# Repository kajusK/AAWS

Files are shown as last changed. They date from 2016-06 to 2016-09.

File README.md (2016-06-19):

Weather Station
===============

Small weather station with many useful features. All mechanical parts
(anemometer, wind vane...) are 3D printed.

Measured values
---------------
* Wind speed (TODO resolution)
* Wind direction (+- 6 degrees)
* Temperature (-40 to 85 °C +-0,1°C)
* Pressure (300 to 1100 hPa +- 6hPa)
* Humidity (0 to 100 %RH +- 2%RH)
* Rain sensor
* Rain (TODO resolution mm/h)

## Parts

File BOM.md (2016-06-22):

Bill Of Material
================

Anemometer
----------
| Item			| Amount|
|---|---|
| Brass knurled nut M3	| 15	|
| Screw M3x10		| 3	|
| Screw M3x30		| 4	|
| Screw M3x25		| 2	|
| Grub screw M3x5	| 1	|
| Rod diameter 4mm	| 45 mm	|
| Bearing 624		| 2	|
| 5MM red LED		| 1	|
| 5MM photodiode	| 1	|

Wind Vane
---------
| Item			| Amount|
|---|---|
| Brass knurled nut M3	| 17	|
| Screw M3x10		| 3	|
| Screw M3x30		| 4	|
| Screw M3x25		| 4	|
| Grub screw M3x5	| 1	|
| Rod diameter 4mm	| 45 mm	|
| Bearing 624		| 2	|
| 5MM red LED		| 5	|
| 5MM photodiode	| 5	|

Rain gauge
----------
| Item			| Amount|
|---|---|
| Threaded rod M4	| 45 mm	|
| Brass knurled nut M3	| 14	|
| Piece of credit card	| 1	|
| Screw M3x10		| 4	|
| Screw M3x20		| 2	|
| Screw M3x45		| 4	|
| Pen spring		| 2	|
| Nut M3		| 2	|
| Washer M3		| 6	|

Sensors housing
---------------
| Item			| Amount|
|---|---|
| Threaded rod M3	| X mm	|
| Nut M3		| X mm	|
| Flower pot saucer	| 6	|
| Small computer fan	| 1	|

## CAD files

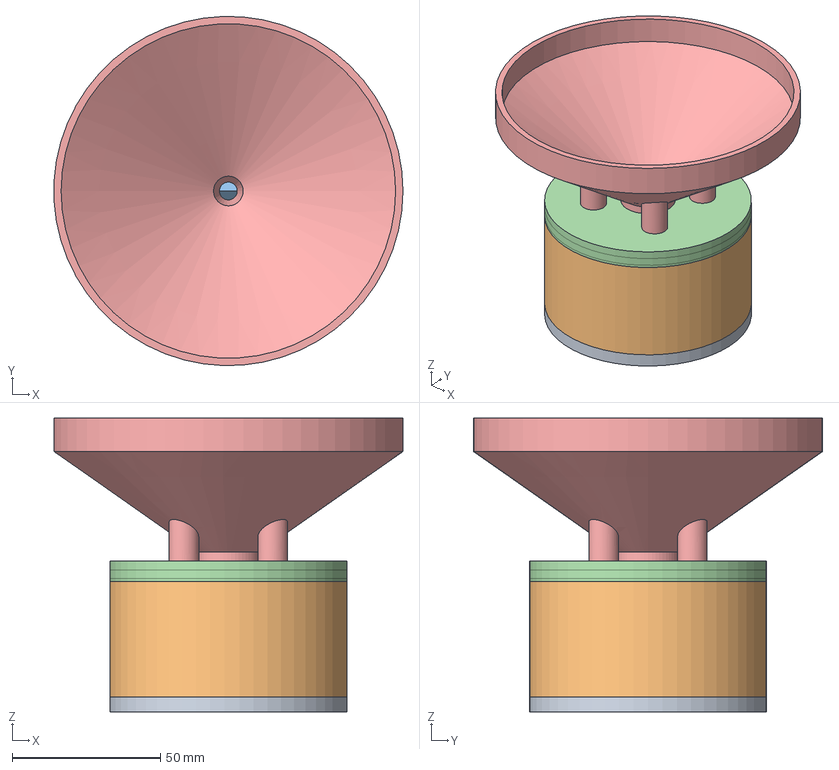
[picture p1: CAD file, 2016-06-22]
cad/rain_gauge/assembly.fcstd
117.9 x 118.0 x 99.3 mm
bottom_01
bucket_01
top_01
catcher_01

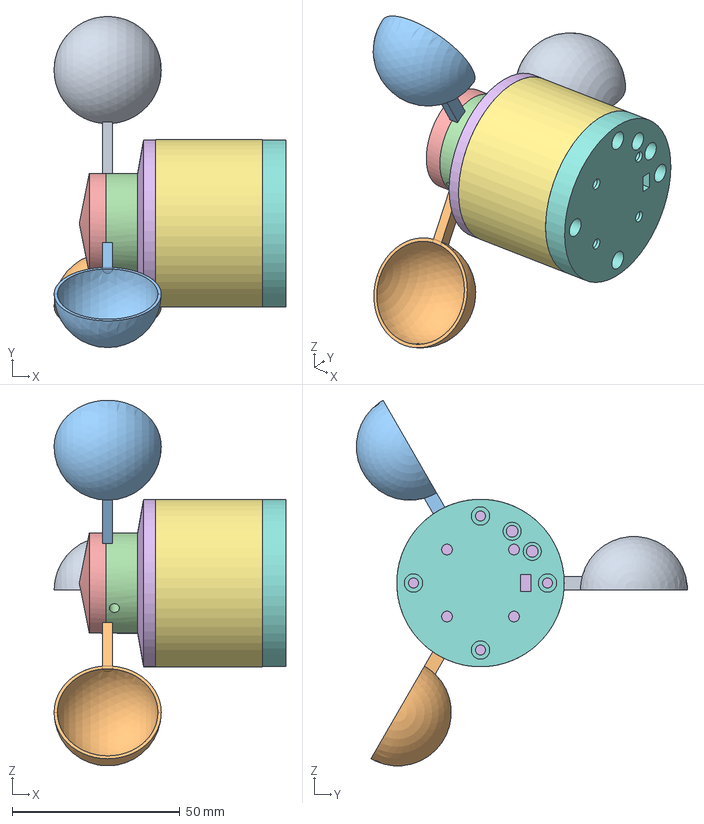
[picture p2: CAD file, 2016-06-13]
cad/anemometer/body/assembly.fcstd
69.2 x 98.8 x 109.1 mm
cup_01
cup_02
cup_03
base_01
top_01
body_top_01
body_bottom_01

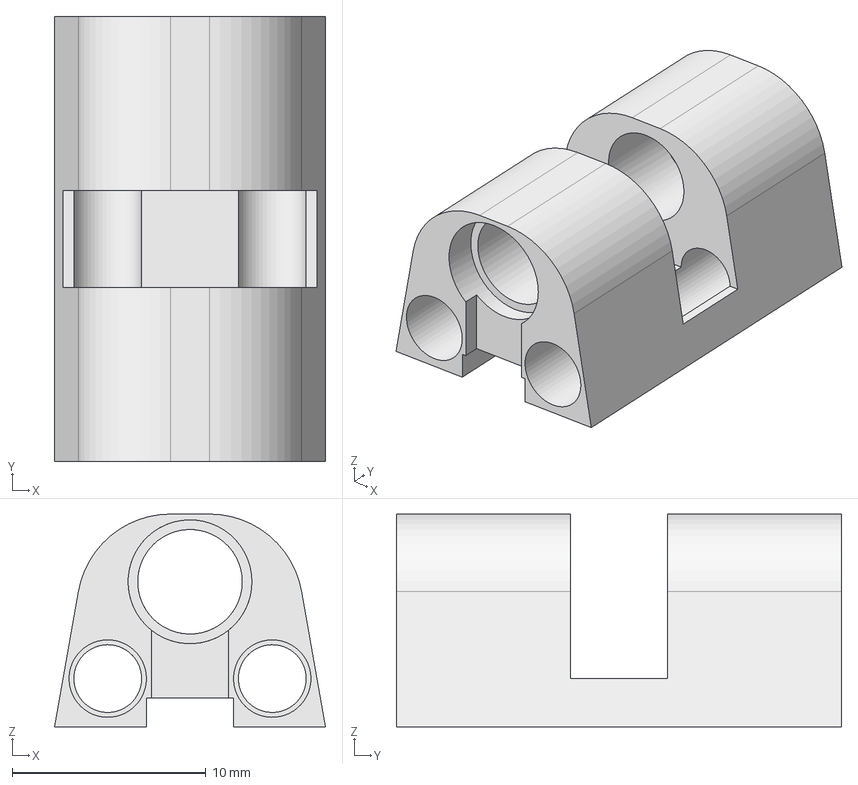
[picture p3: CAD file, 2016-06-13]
cad/anemometer/body/sensor_holder.fcstd
14.0 x 23.0 x 11.0 mm

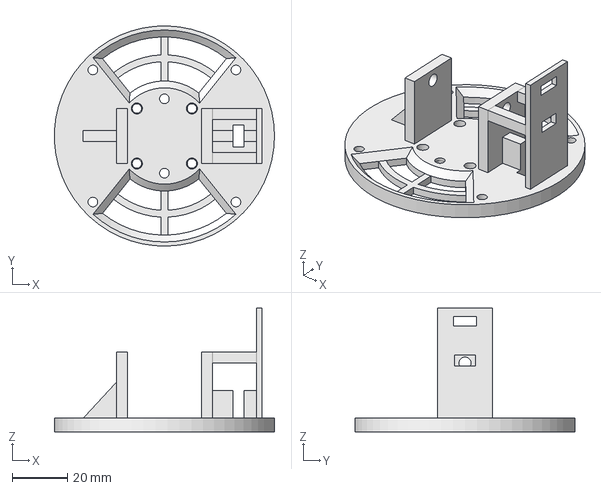
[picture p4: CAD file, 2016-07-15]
cad/rain_gauge/bottom.fcstd
79.9 x 80.0 x 45.0 mm

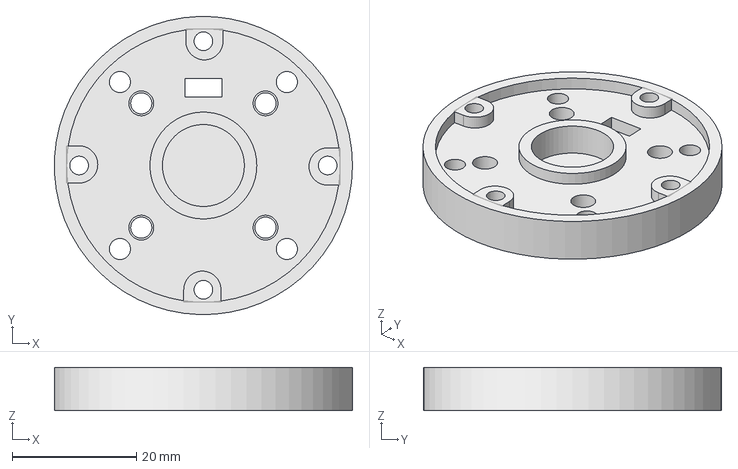
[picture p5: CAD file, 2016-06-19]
cad/wind_vane/body/body_bottom.fcstd
48.0 x 48.0 x 7.00 mm

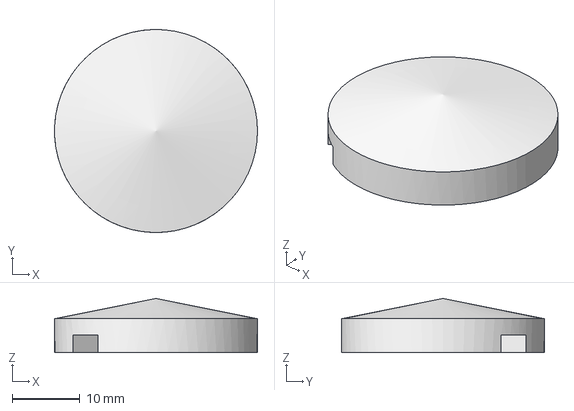
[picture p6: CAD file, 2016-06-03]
cad/wind_vane/top/top.fcstd
30.0 x 30.0 x 8.00 mm

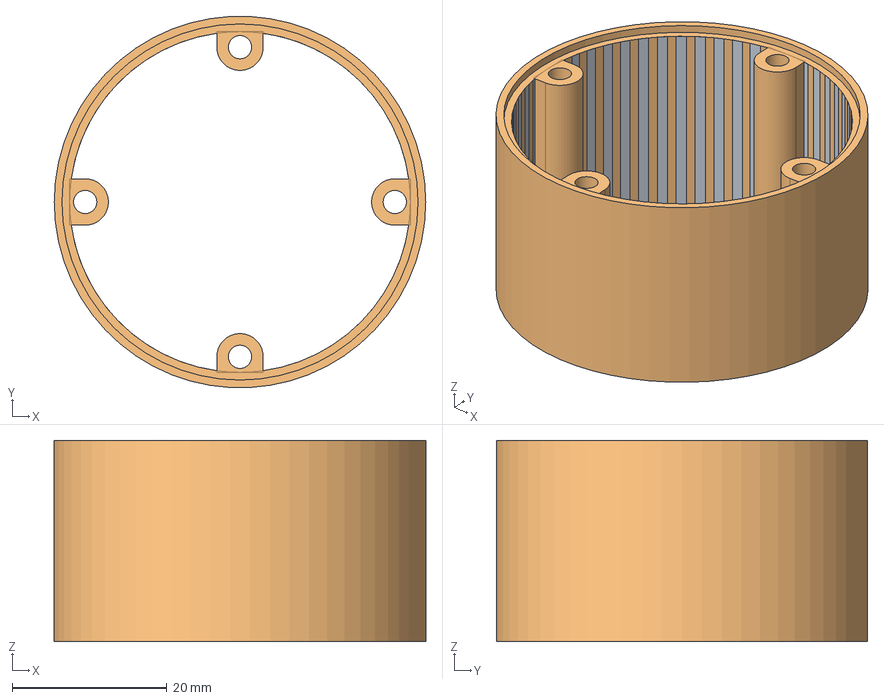
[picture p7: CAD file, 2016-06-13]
cad/anemometer/body/body.fcstd
48.0 x 47.9 x 26.0 mm
PolarPattern

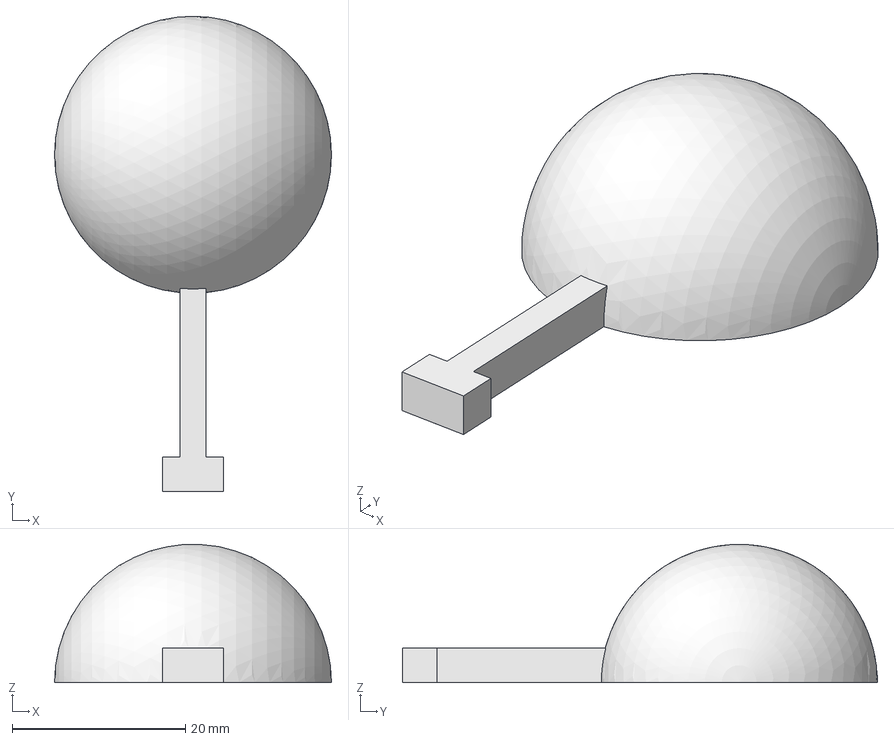
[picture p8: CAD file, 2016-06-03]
cad/anemometer/top/cup.fcstd
32.0 x 54.9 x 16.0 mm

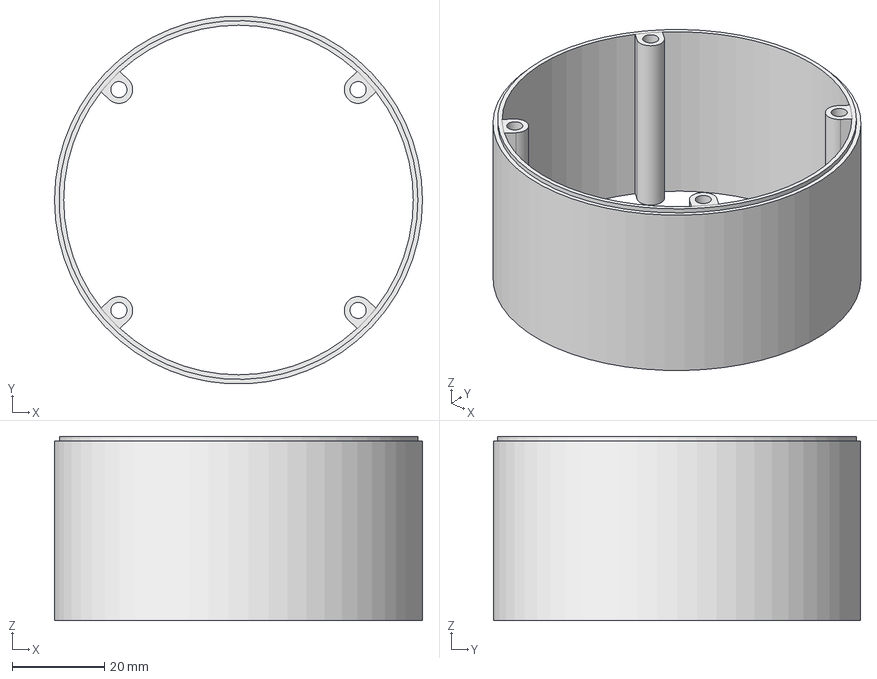
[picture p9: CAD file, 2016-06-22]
cad/rain_gauge/body.fcstd
80.0 x 79.9 x 40.0 mm

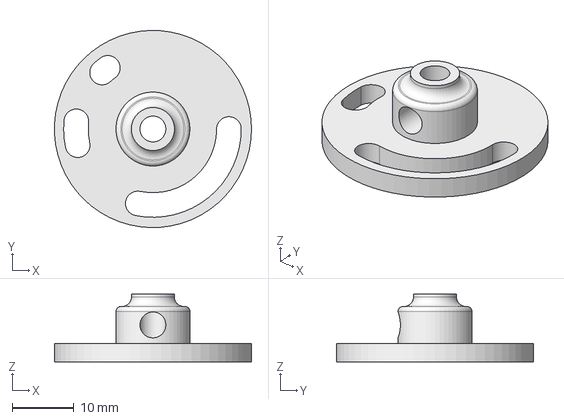
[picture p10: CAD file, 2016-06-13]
cad/wind_vane/body/signal_plate.fcstd
32.0 x 32.0 x 11.0 mm

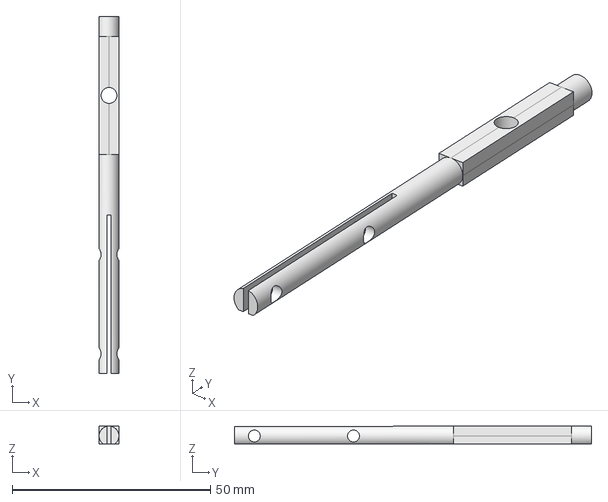
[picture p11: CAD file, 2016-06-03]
cad/wind_vane/top/rod.fcstd
5.00 x 90.0 x 4.50 mm

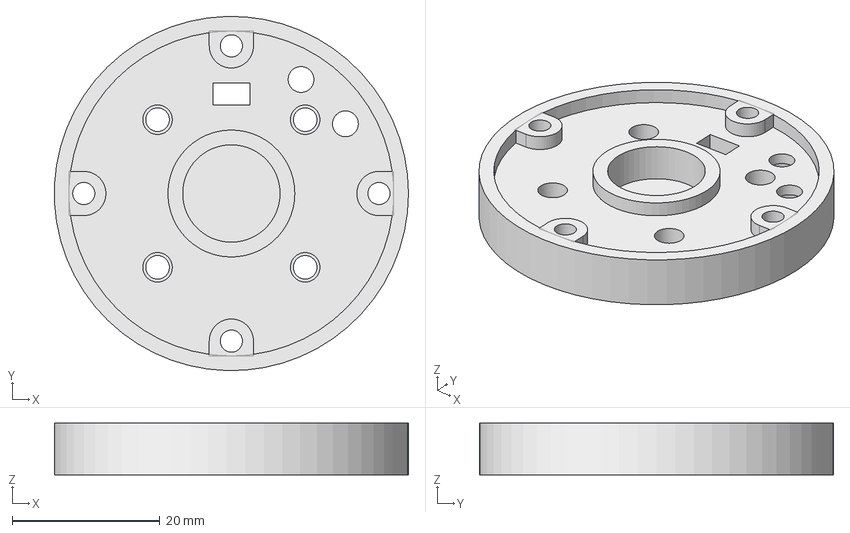
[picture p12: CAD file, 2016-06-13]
cad/anemometer/body/body_bottom.fcstd
48.0 x 48.0 x 7.00 mm

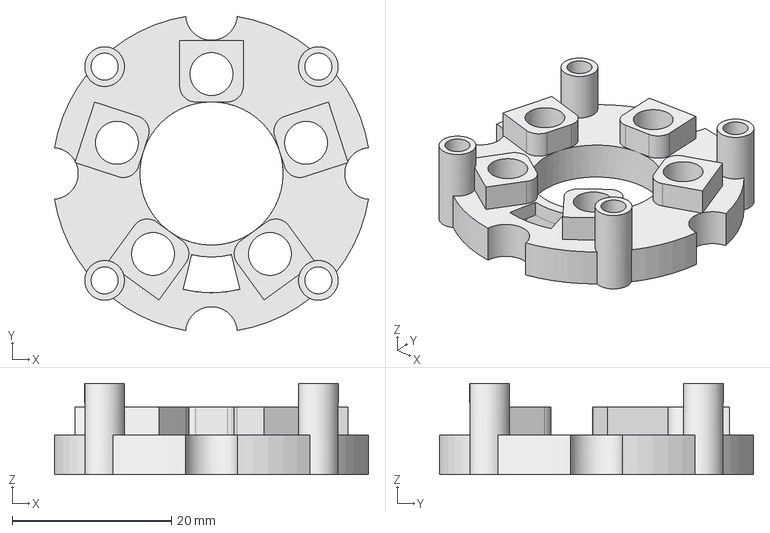
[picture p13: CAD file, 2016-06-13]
cad/wind_vane/body/sensor_holder.fcstd
39.5 x 39.5 x 11.5 mm

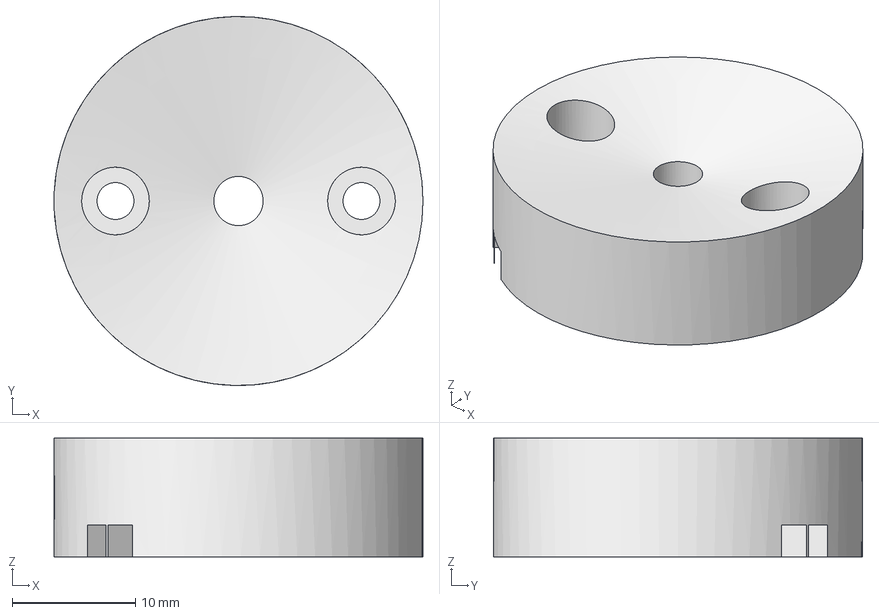
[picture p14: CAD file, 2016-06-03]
cad/wind_vane/top/base.fcstd
30.0 x 30.0 x 9.64 mm

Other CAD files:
cad/anemometer/body/body_top.fcstd
cad/rain_gauge/top.fcstd
cad/wind_vane/top/vane.fcstd
cad/rain_gauge/catcher.fcstd
cad/anemometer/body/body.stl
cad/anemometer/body/body_bottom.stl
cad/anemometer/body/body_top.stl
cad/anemometer/body/sensor_holder.stl
cad/anemometer/body/signal_plate.fcstd
cad/anemometer/body/signal_plate.stl
cad/anemometer/top/base.fcstd
cad/anemometer/top/base.stl
cad/anemometer/top/cup.stl
cad/anemometer/top/top.fcstd
cad/anemometer/top/top.stl
cad/rain_gauge/body.stl
cad/rain_gauge/bottom.stl
cad/rain_gauge/bucket.fcstd
cad/rain_gauge/bucket.stl
cad/rain_gauge/catcher.stl
cad/rain_gauge/top.stl
cad/wind_vane/body/body_bottom.stl
cad/wind_vane/body/sensor_holder.stl
cad/wind_vane/body/signal_plate.stl
cad/wind_vane/top/base.stl
cad/wind_vane/top/rod.stl
cad/wind_vane/top/top.stl
cad/wind_vane/top/vane.stl

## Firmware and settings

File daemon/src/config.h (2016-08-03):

/*
 * Weather station
 *
 * For license, see LICENSE.txt
 *
 * Jakub Kaderka 2016
 */
#ifndef __CONFIG_H_
#define __CONFIG_H_

#define DEFAULT_SQLITE_FILE "/var/lib/aaws/weather.db"
#define DEFAULT_LIVE_FILE "/var/lib/aaws/live.txt"
#define DEFAULT_SERIAL "/dev/ttyAMA0"
#define DEFAULT_PID_FILE "/var/run/weatherd.pid"
#define DEFAULT_LOG_FILE "/var/log/weatherd.log"
#define DEFAULT_BAUDR 9600
#define DEFAULT_SAVE_PERIOD 5*60
#define DEFAULT_ELEVATION -1000

enum e_backends {
	B_SQLITE = 1 << 0,
	B_MYSQL = 1 << 1,
	B_LIVE = 1 << 2,
	B_WUNDERGROUND = 1 << 3,
	B_OWEATHERMAP = 1 << 4,
};

/* Credentials for wunderground, openweathermap... */
struct s_creds {
	char username[32];
	char password[32];
};

struct s_db {
	char username[32];
	char password[32];
	char host[64];
	char database[32];

};

struct s_station {
	char latitude[32];
	char longitude[32];
	int elevation;
	char name[64];
};

struct s_config {
	char serial[256];
	int baudr;
	char pid_file[256];
	char log_file[256];
	int save_period;

	struct s_station station;

	/* backends configuration */
	enum e_backends backends;	/* bit mask of enabled backends */
	char sqlite_path[256];		/* path to sqlite database */
	struct s_db mysql;
	char live_path[256];		/* path to live file */
	struct s_creds wunderground;
	struct s_creds oweathermap;
};


/*
 * Read config from filename, use default values where not defined
 */
extern int conf_read(char *filename);

/*
 * Get config readed by conf_read
 */
extern struct s_config *conf_get(void);

#endif

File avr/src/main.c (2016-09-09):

/*
 * Weather station with serial output
 *
 * temperature -40 to 85 (+-0,5) °C
 * air pressure 300 to 1100 (+-6) hPa
 * humidity 0-100 (+-2) %RH
 * snow depth 0-500 cm (+-3mm)
 *
 * Communication:
 * ==============
 * Data format:
 * ------------
 * #T:23.5;H:32;P:1013.25;R:2.55;W:11.5;D:E;U:5.6;S:12.5;@
 *
 * Explanation:
 * # - start of the message
 * T - temperatur in °C
 * H - humidity in %RH
 * P - absolute pressure in hPa
 * R - rain counter since last reset in mm
 * W - wind speed in m/s
 * D - wind direction in degrees
 * U - UV index (0-15)
 * S - Snow depth in cm
 * @ - end of message
 * E - error, sensor dead
 *
 * Ack reply:
 * ----------
 * #A;@ - ACK
 * #N;@ - NACK - unknown command, etc
 *
 * Firmware version
 * ----------------
 * #V:1.2;@
 *
 * Commands:
 * ---------
 * #R;@ - reset rain counter (e.g. every hour...), responds with ACK
 * #T;@ - test if station is alive, responds with ACK
 * #V;@ - firmware version
 * #C;@ - calibrate no snow distance - current distance is saved as 0cm.
 *
 * For license, see LICENSE.txt
 *
 * Jakub Kaderka 2016
 */

#include <stdio.h>
#include <stdlib.h>
#include <inttypes.h>
#include <string.h>
#include <avr/sleep.h>
#include <avr/interrupt.h>
#include <avr/power.h>
#include <util/delay.h>

#include "config.h"
#include "bmp180.h"
#include "dht22.h"
#include "rain.h"
#include "wind.h"
#include "ml8511.h"
#include "utils/uart.h"
#include "snow.h"

#define SEND_DELAY 5

enum sensor_state {
	E_INITBMP180 = 1 << 0,
	E_BMP180 = 1 << 1,
	E_DHT22 = 1 << 2,
};

ISR(BADISR_vect)
{

}

static void print_decimal(char *buffer, uint8_t decimals)
{
	uint8_t i = 0;

	if (strlen(buffer) <= decimals) {
		putchar('0');
	} else {
		for (; i < strlen(buffer) - decimals; i++)
			putchar(buffer[i]);
	}

	if (!decimals)
		return;

	putchar('.');
	for ( ; i < strlen(buffer); i++ )
		putchar(buffer[i]);
}

/*
 * Print integer to stdout, insert dot to separated decimals
 */
static void print_num(int num, uint8_t decimals)
{
	char buffer[9];
	itoa(num, buffer, 10);
	print_decimal(buffer, decimals);
}

static void print_32num(uint32_t num, uint8_t decimals)
{
	char buffer[9];
	ultoa(num, buffer, 10);
	print_decimal(buffer, decimals);
}

static void check_rx(void)
{
	char command;

	if (uart_check_rx() == 0 || getchar() != '#')
		return;

	//avoid deadlock when no more data arrived
	if (uart_check_rx() == 0) {
		_delay_ms(10);
		if (uart_check_rx() == 0)
			return;
	}

	command = getchar();
	putchar('#');
	switch (command) {
	case 'R':
		rain_reset();
		putchar('A');
		break;
	case 'T':
		rain_reset();
		putchar('A');
		break;
	case 'C':
		snow_calibrate();
		putchar('A');
		break;
	case 'V':
		fputs("V:"VERSION, stdout);
		break;
	default:
		putchar('N');
	}
	fputs(";@", stdout);

	while (uart_check_rx() != 0 && getchar() != '@')
		;
}

static enum sensor_state send_data(enum sensor_state state)
{
	int16_t temp_bmp;
	int16_t temp;
	int16_t snow;
	uint32_t pres;
	uint16_t hum;
	uint8_t uv;

	state = state & E_INITBMP180;
	if (state & E_INITBMP180 || bmp180_read(&temp_bmp, &pres) != 0)
		state |= E_BMP180;
	if (dht22_read(&temp, &hum) != 0)
		state |= E_DHT22;

	putchar('#');

	fputs("P:", stdout);
	if (state & E_BMP180)
		putchar('E');
	else
		print_32num(pres, 2);

	fputs(";T:", stdout);
	if (state & E_DHT22) {
		if (state & E_BMP180)
			putchar('E');
		else
			print_num(temp_bmp, 1);

		fputs(";H:E", stdout);
	} else {
		print_num(temp, 1);
		fputs(";H:", stdout);
		print_num(hum, 1);
	}

	fputs(";W:", stdout);
	print_num(wind_speed(), 1);
	fputs(";D:", stdout);
	print_num(wind_dir(), 0);

	fputs(";R:", stdout);
	print_num(rain_get(), 1);

	fputs(";U:", stdout);
	uv = ml8511_get();
	if (uv == 0xff)
		putchar('E');
	else
		print_num(uv, 1);

	fputs(";S:", stdout);
	snow = snow_get();
	if (snow == 0xffff)
		putchar('E');
	else
		print_num(snow, 1);

	fputs(";@\n", stdout);

	// if bmp180 failed, try to init again
	if (state & E_INITBMP180 && bmp180_init() == 0)
		state &= ~E_INITBMP180;

	return state;
}

int main(int argc, char *argv[])
{
	enum sensor_state state = 0;
	int i;

	//TODO detect type of reset (watchdog....)
	uart_init();
	sei();

	fputs("Weather station, FW version " VERSION"\n\r", stdout);
	fputs("Kajus 2016\n\r", stdout);

	if (bmp180_init() != 0) {
		state |= E_INITBMP180;
		fputs("Unable to init bmp180", stderr);
	}

	rain_init();
	wind_init();
	snow_init();

	puts("Init done");

	//set_sleep_mode()

	while (1) {
		state = send_data(state);
		for (i = 0; i < SEND_DELAY*10; i++) {
			check_rx();
			_delay_ms(100);
		}
	}

	return 0;
}

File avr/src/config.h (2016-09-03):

/* definitions to keep the things sane, don't modify */
#define PORT_(port)	PORT ## port
#define DDR_(port)	DDR  ## port
#define PIN_(port)	PIN  ## port

#define PORT(port)	PORT_(port)
#define DDR(port)	DDR_(port)
#define PIN(port)	PIN_(port)

#define VERSION	"0.1"

// serial baudrate
#define BAUD	9600

//supply voltage - used in ADC calculations, should be between 3.3 and 5
#define VCC_VOLTAGE 5

/*
 * Wind speed calibration
 *
 * Take several measurements of wind speed (e.g. by car with wind sensor mounted
 * on roof) and calculate correction:
 *
 * Some equation
 */
#define WIND_CORRECTION 1234

/*
 * Rain calibration
 *
 * Pour known amount of water (e.g. equal to 20mm of rainfalls) to your
 * rain gauge and measure a number of pulses generated by the tipping bucket.
 *
 * Calculate pulses per mm and round to hundreds of mm
 * mm_per_pulse = used_water / number_of_pulses
 */
#define RAIN_MM_PER_PULSE 10

/*
 * IO definitions
 */
// dht22 - humidity and temp
#define DHT22_PORT	D
#define DHT22		5

//wind dir, requires 5 pins in a row, define first pin and gate, the defined
//pin and folowing 4 will be used, e.g. 2 means pins 2,3,4,5,6 will be used
#define WIND_DIR_PORT	A
#define WIND_DIR_START	0

//rain sensor is tied to INT pin, select either INT0 or INT1
#define RAIN_INT 0

//snow sensor is tied to INT pin, select either INT0 or INT1, must differ from
//RAIN_INT
#define SNOW_INT 1
//ignore any value below this one to avoid noise recognized as snow, in tenths
//of cm
#define SNOW_IGNORE 5
//trigger of ultrasonic snow measurements
#define ULTRAS_TRIG_PORT	D
#define ULTRAS_TRIG		6

//ml8511 adcX port
#define ML8511_ADC 7

//wind speed sensor is using pin ICP1

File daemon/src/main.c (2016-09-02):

/*
 * Weather station
 *
 * For license, see LICENSE.txt
 *
 * Jakub Kaderka 2016
 */

#include <stdio.h>
#include <sys/stat.h>
#include <stdlib.h>
#include <unistd.h>
#include <signal.h>
#include <string.h>

#include "utils/weather.h"
#include "utils/serial.h"
#include "station.h"
#include "config.h"
#include "backends/backends.h"

#define AAWS_VERSION "0.1"
#define CONF_DEFAULT "/etc/aaws/config"
#define SAMPLE_PERIOD 5
#define RETRY_INTERVAL 10

static int serial_fd = -1;

static void sig_handler(int signum)
{
	fprintf(stderr, "SIGINT received, exiting...\n");
	serial_close(serial_fd);

	exit(0);
}

static int daemonize(char *pid_file, char *log)
{
	FILE *f;
	pid_t pid, sid;

	pid = fork();
	if (pid < 0) {
		fprintf(stderr, "Unable to fork, running in foreground...\n");
		return -1;
	}

	if (pid > 0) {
		f = fopen(pid_file, "w");
		if (f == NULL) {
			serial_close(serial_fd);
			fprintf(stderr, "Unable to create pid file, ending\n");
			exit(1);
		}
		fprintf(f, "%d", pid);
		fclose(f);

		printf("%d\n", pid);
		exit(0);
	}

	/* child code */
	umask(0);
	sid = setsid();
	if (sid < 0)
		fprintf(stderr, "Warning: unable to create new session\n");

	if (chdir("/var") < 0)
		fprintf(stderr, "Warning: unable to change directory\n");

	if (log != NULL) {
		if (freopen(log, "a", stdout) == NULL)
			fprintf(stderr, "Warning: unable to redirect stdout\n");
		if (freopen(log, "a", stderr) == NULL)
			fprintf(stderr, "Warning: unable to redirect stderr\n");
	}

	close(STDOUT_FILENO);
	close(STDERR_FILENO);
	close(STDIN_FILENO);

	return 0;
}

static void usage(const char *name)
{
	fprintf(stderr,
		"AAWS - weather station recording daemon\n"
		"Usage: %s [-c filename]\n\n"
		"Options:\n"
		"  -h\t\t\tShow this help and exit\n"
		"  -v\t\t\tPrint version info and exit\n"
		"  -t\t\t\tTest configuraion and exit\n"
		"  -c filename\t\tSet config file (default "CONF_DEFAULT")\n"
		"  -f\t\t\tRun in foreground\n", name);
}

static void loop(int fd, struct s_config *conf)
{
	int cycles = 0;
	int hour_counter = 0;
	struct s_message data;
	struct s_weather weather;
	float rain_prev = 0;
	float rain_1h = 0;

	memset(&weather, 0, sizeof(weather));
	weather.valid = ~0;

	while (1) {
		data = station_read(fd);

		if (data.val.wind_speed > weather.data.wind_gusts) {
			weather.data.wind_gusts_dir = data.val.wind_dir;
			weather.data.wind_gusts = data.val.wind_speed;
		}
		//average data
		weather.data.wind_speed += data.val.wind_speed;
		weather.data.wind_dir += data.val.wind_dir;
		weather.data.humidity += data.val.humidity;
		weather.data.temp += data.val.temp;
		weather.data.pressure += data.val.pressure;
		weather.data.uv += data.val.uv;

		if (!(data.pres & P_TEMP) || (data.err & E_TEMP))
			weather.valid &= ~(V_TEMP | V_DEW_POINT);
		if (!(data.pres & P_PRESSURE) || (data.err & E_PRESSURE))
			weather.valid &= ~V_PRESSURE;
		if (!(data.pres & P_HUMIDITY) || (data.err & E_HUMIDITY))
			weather.valid &= ~(V_HUMIDITY | V_DEW_POINT);
		if (!(data.pres & P_UV) || (data.err & E_UV))
			weather.valid &= ~V_UV;
		if (!(data.pres & P_WIND_DIR) || (data.err & E_WIND_DIR))
			weather.valid &= ~(V_WIND_DIR | V_WIND_GUSTS_DIR);
		if (!(data.pres & P_WIND_SPEED) || (data.err & E_WIND_SPEED))
			weather.valid &= ~(V_WIND_SPEED | V_WIND_GUSTS | V_WIND_GUSTS_DIR);
		if (!(data.pres & P_RAIN) || (data.err & E_RAIN))
			weather.valid &= ~(V_RAIN & V_RAIN_1H);

		sleep(SAMPLE_PERIOD);
		cycles++;
		hour_counter++;

		//save period elapsed
		if (cycles >= conf->save_period/SAMPLE_PERIOD) {
			//get average
			weather.data.wind_speed = weather.data.wind_speed / cycles;
			weather.data.wind_dir = weather.data.wind_dir / cycles;
			weather.data.humidity = weather.data.humidity / cycles;
			weather.data.temp = weather.data.temp / cycles;
			weather.data.uv = weather.data.uv / cycles;

			weather.data.pressure = weather.data.pressure / cycles;
			weather.data.pressure = press_relative(weather.data.pressure, conf->station.elevation);
			weather.data.dew_point = dew_point(weather.data.humidity, weather.data.temp);
			weather.data.rain_1h = rain_1h;

			//get rain intensity in last SAVE_PERIOD
			weather.data.rain = (data.val.rain - rain_prev)*3600.0/conf->save_period;

			backends_send(&weather, conf);

			//clear stuff
			memset(&weather, 0, sizeof(weather));
			weather.valid = ~0;
			rain_prev = data.val.rain;

			cycles = 0;
		}

		//one hour elapsed
		if (hour_counter >= 3600/SAMPLE_PERIOD){
			hour_counter = 0;
			rain_1h = data.val.rain;
			backends_add_rain(data.val.rain);

			station_rain_reset(fd);
			rain_prev = 0;
		}
	}
}

int main(int argc, char **argv)
{
	int opt;
	char *conf_filename = CONF_DEFAULT;
	int test_config = 0;
	int daemon = 1;
	struct s_config *conf;

	while((opt = getopt(argc, argv, "hc:tfv")) != -1) {
		switch (opt) {
		case 'h':
			usage(argv[0]);
			exit(0);
			break;
		case 'v':
			printf("AAWS version: "AAWS_VERSION"\n");
			exit(0);
			break;
		case 't':
			test_config = 1;
			break;
		case 'f':
			daemon = 0;
			break;
		case 'c':
			conf_filename = optarg;
			break;
		default:
			usage(argv[0]);
			exit(-1);
		}
	}

	if (conf_read(conf_filename) != 0) {
		fprintf(stderr, "Incorrect config file, ending...\n");
		exit(-1);
	}

	if (test_config) {
		printf("Config file is OK\n");
		exit(0);
	}

	conf = conf_get();

	if (backends_init(conf) != 0)
		exit(-1);
	if ((serial_fd = serial_open(conf->serial, conf->baudr)) < 0)
		exit(-1);

	signal(SIGINT, sig_handler);

	printf("Checking station status\n");
	while (!station_alive(serial_fd)) {
		fprintf(stderr, "Station is not responding, "
			"trying again in %d seconds...\n", RETRY_INTERVAL);
		sleep(RETRY_INTERVAL);
	}
	/* Reset rain, don't know for how long it was running without reset */
	station_rain_reset(serial_fd);

	printf("Entering main loop\n");
	if (daemon)
		daemonize(conf->pid_file, conf->log_file);

	loop(serial_fd, conf);

	return 0;
}

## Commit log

2015-12-31 Fixed programmer can't recognize the MCU any more
    If the MCU is running on internal oscilator, MCLR is used
    as I/O, and Timer1 enabled, the pickit can't recognize the
    MCU any more, fixed by enabling MCLR again
2016-01-31 Switched from PIC to attiny, dht22 working
2016-04-28 Added return value to i2c functions
2016-05-24 bmp180 fixed, added return value
    [bmp180.c]
2016-05-24 Fixed accuracy of bmp180
    [bmp180.c]
2016-06-03 Added anemometer
    [base.fcstd, base.stl, cup.fcstd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]
2016-06-03 Added wind wane top
    [base.fcstd, base.stl, rod.fcstd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]
2016-06-13 Anemometer body added
    [assembly.fcstd, body.fcstd, body_bottom.fcstd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]
2016-06-13 Simplified anemometer body to print without supports
    [assembly.fcstd, body.fcstd, body_bottom.fcstd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]
2016-06-13 Added sensor holder for anemometer body
    [assembly.fcstd, body_bottom.fcstd, sensor_holder.fcstd]
2016-06-13 Decreased wall width
    [body.fcstd, body_bottom.fcstd, body_top.fcstd]
2016-06-13 Generated stl for anemometer body
    [body.fcstd, body.stl, body_bottom.fcstd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]
2016-06-13 Fixed sensor holder and body dimensions
    [body.fcstd, body.stl, sensor_holder.fcstd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]
2016-06-13 Added body parts for wind vane
    [body_bottom.fcstd, sensor_holder.fcstd, signal_plate.fcstd]
2016-06-19 Fixed bottom dimensions
    [body_bottom.fcstd]
2016-06-19 Added stl files for wind vane
    [body_bottom.stl, sensor_holder.stl, signal_plate.stl]
2016-06-19 Added readme and bill of materials
2016-06-22 updated BOM
2016-06-22 Rain gauge (tipping bucket) added
    [assembly.fcstd, body.fcstd, body.stl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]
2016-06-26 Pressure changed to relative pressure
2016-06-26 Rounded pressure to one decimal
2016-07-03 Reset rain counter added
    [station.h]
2016-07-08 error messages cleanup in daemonize
    [main.c]
2016-07-08 Fixed serial close on exit
    [main.c]
2016-07-09 Base64 encoder for http auth added
2016-07-12 Moved i2c and uart to utils
2016-07-12 Serial renamed to uart
2016-07-13 Printing measured data works
2016-07-15 Added hole for cables to raing gauge bottom
    [bottom.fcstd, bottom.stl]
2016-07-17 Send error when sensor dies
    [main.c]
2016-07-24 Store relative pressure in DB
2016-08-03 Error reporting on sensor malofunction added
    [main.c]
2016-08-03 Fixed accuracy in main comments
    [main.c]
2016-08-03 fixed amount of parameters for sqlite insert
2016-08-03 Fixed division by zero in main loop
    [main.c]
2016-08-19 added support for INT1/INT0 rain sensor
2016-08-31 added reading errors in station messages
    [main.c, station.h]
2016-08-31 Added disabling error or missing sensors in deamon backends
    [main.c]
2016-09-02 Reset rain when turned on
    [main.c]
2016-09-09 Ultrasonic reading update
